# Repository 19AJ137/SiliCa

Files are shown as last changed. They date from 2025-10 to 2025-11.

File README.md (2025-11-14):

# SiliCa

`SiliCa` は、JIS X 6319-4（`FeliCa`）互換の非接触型 IC カードです。  
マイコンとして `ATtiny1616` を採用しており、外部電源を必要とせず、カードリーダからの給電によって動作します。

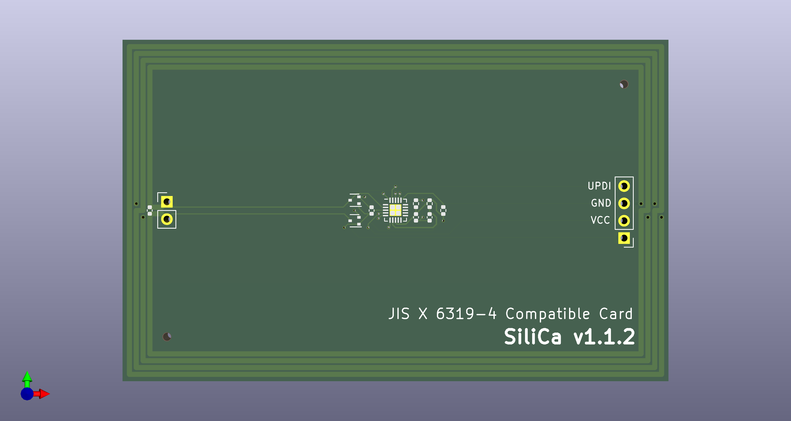
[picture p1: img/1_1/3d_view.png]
3D View


## 概要

`SiliCa` は、最小限のハードウェア構成で、 `FeliCa` プロトコルをファームウェアによって再現し、`FeliCa Standard` や `FeliCa Lite-S` のエミュレーションを実現することを目的としています。

また、`SiliCa` では、実際の `FeliCa` カードで書き換えが不可能な `IDm` やシステムコードなどのパラメータを自由に書き換えることができます。

詳細な仕様や使用方法については、寄稿した同人誌 [rand_r(&v3)](https://techbookfest.org/product/an6q3RzcSM0RcWQBevrEM9) をご参照ください。

## 回路図

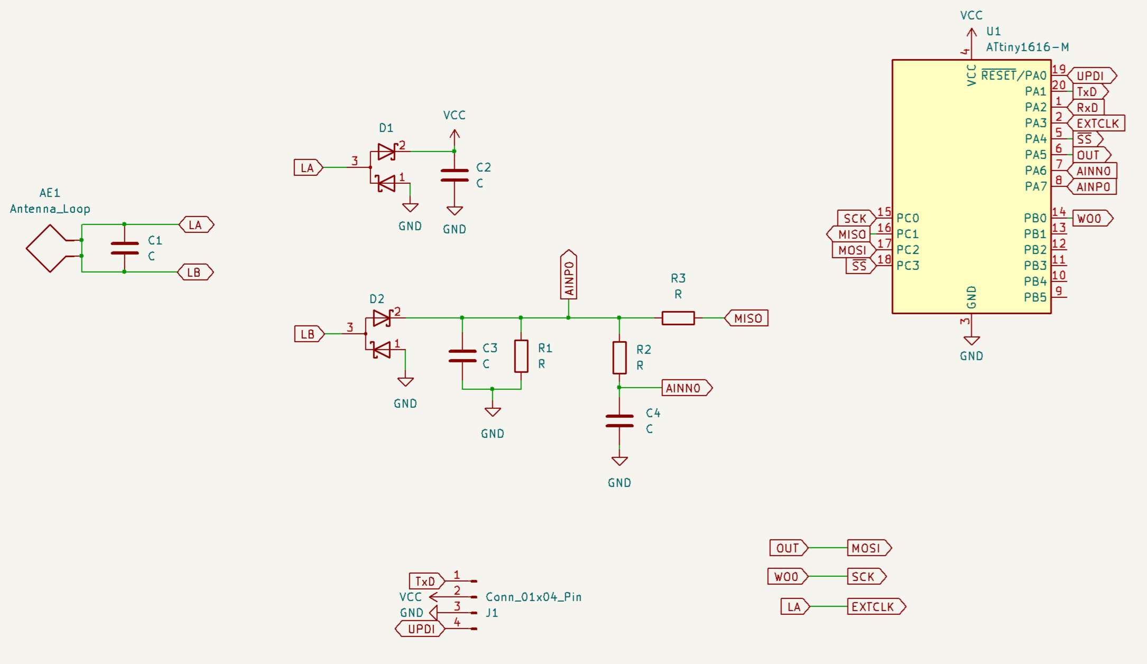
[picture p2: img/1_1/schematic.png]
Schematic


## 注意事項

本プロジェクトは、学術的および実験的な目的で提供されており、商業利用や実際の運用を目的としたものではありません。

---

```
FeliCaは、ソニー株式会社が開発した非接触ICカードの技術方式です。
FeliCaは、ソニーグループ株式会社の登録商標です。
本文では™、®は明記していません。
```

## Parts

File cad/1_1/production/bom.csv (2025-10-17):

Designator | Footprint | Quantity | Value | LCSC Part #
AE1 | PinHeader_1x02_P2.54mm_Vertical | 1 | Antenna_Loop
C1 | 0402 | 4 | C | C1567
C2 | 0402 | 4 | C | C15195
C3 | 0402 | 4 | C | C1523
C4 | 0402 | 4 | C | C1523
D1 | SOT-523 | 2 | D_Schottky_Dual_Series_AKC_Parallel | C2919808
D2 | SOT-523 | 2 | D_Schottky_Dual_Series_AKC_Parallel | C2919808
J1 | PinHeader_1x04_P2.54mm_Vertical | 1 | Conn_01x04_Pin
R1 | 0402 | 3 | R | C11702
R2 | 0402 | 3 | R | C11702
R3 | 0402 | 3 | R | C25123
U1 | VQFN-20-1EP_3x3mm_P0.4mm_EP1.7x1.7mm | 1 | ATtiny1616-M | C507118

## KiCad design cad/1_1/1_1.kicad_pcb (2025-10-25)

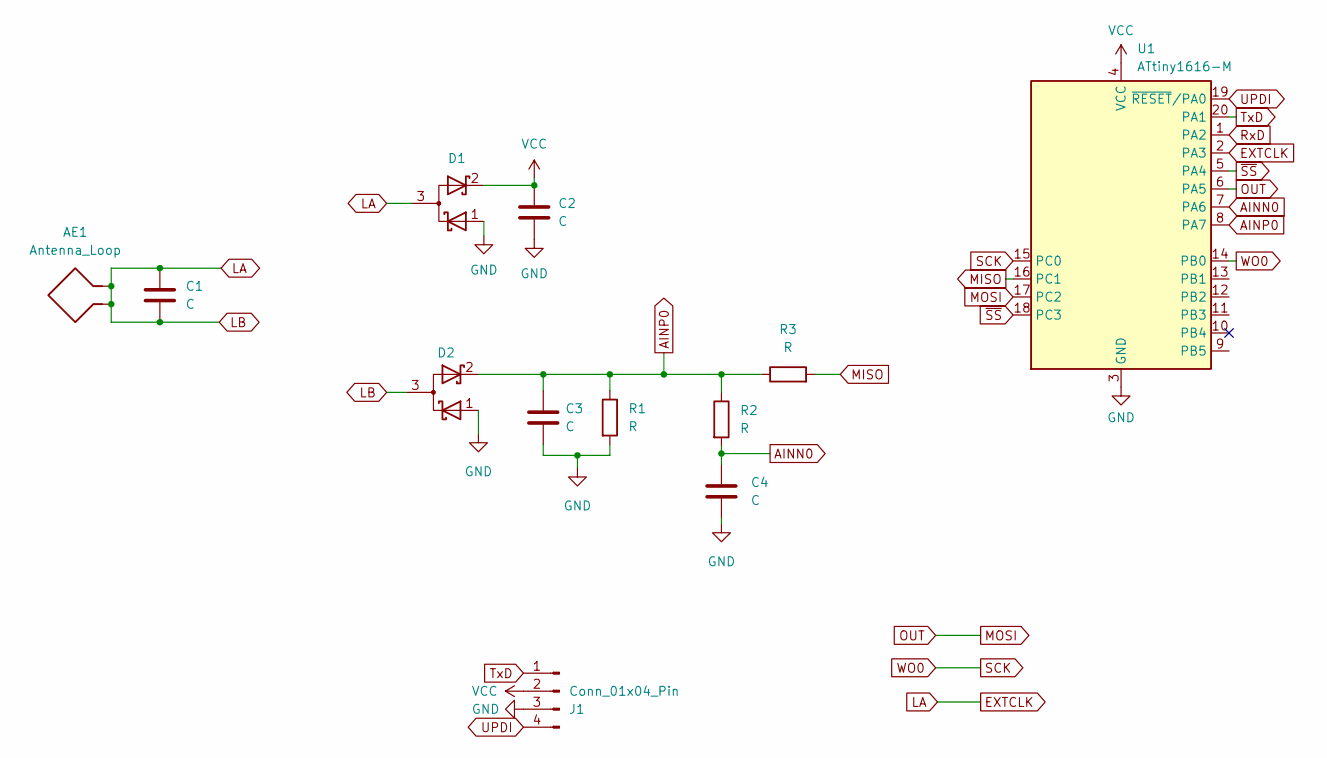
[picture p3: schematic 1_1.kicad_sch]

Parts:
AE1: Antenna_Loop; PinHeader_1x02_P2.54mm_Vertical
C1, C2, C3, C4: C; C_0402_1005Metric
D1, D2: D_Schottky_Dual_Series_AKC_Parallel; SOT-523
J1: Conn_01x04_Pin; PinHeader_1x04_P2.54mm_Vertical
R1, R2, R3: R; R_0402_1005Metric
U1: ATtiny1616-M; VQFN-20-1EP_3x3mm_P0.4mm_EP1.7x1.7mm

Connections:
AINN0: C4.1, R2.2, U1.7 (PA6)
AINP0: C3.1, D2.2 (K), R1.1, R2.1, R3.1, U1.8 (PA7)
EXTCLK: AE1.1, AE1.2, C1.1, C1.2, D1.3 (A), D2.3 (A), U1.2 (PA3)
GND: C2.2, C3.2, C4.2, D1.1 (K), D2.1 (K), J1.3, R1.2, U1.3 (GND), U1.21 (GND)
MISO: R3.2, U1.16 (PC1)
MOSI: U1.6 (PA5), U1.17 (PC2)
RxD: U1.1 (PA2)
SCK: U1.14 (PB0), U1.15 (PC0)
TxD: J1.1, U1.20 (PA1)
UPDI: J1.4, U1.19 (~RESET/PA0)
VCC: C2.1, D1.2 (K), J1.2, U1.4 (VCC)
~SS: U1.5 (PA4), U1.18 (PC3)

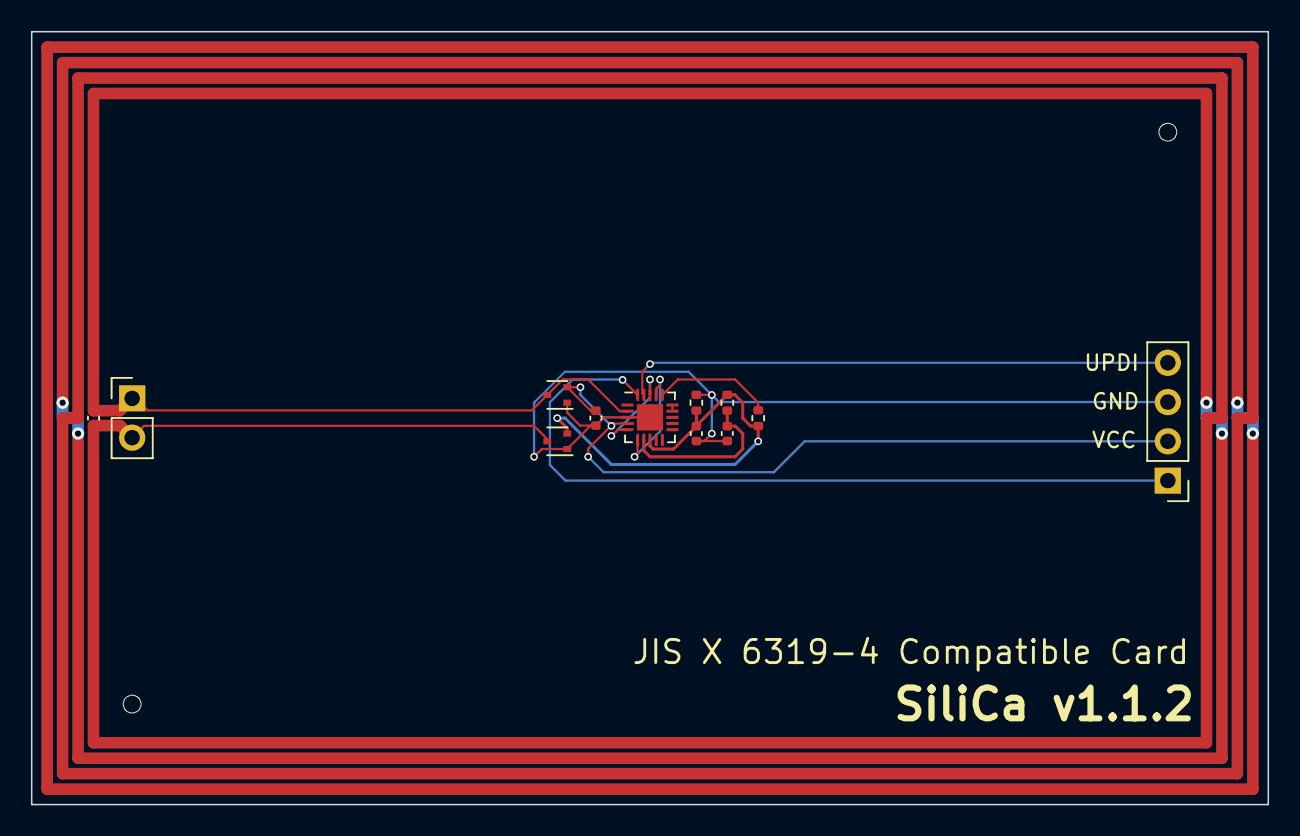
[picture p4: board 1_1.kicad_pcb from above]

Board: 2 copper layers, 80.0 x 50.0 mm, 12 parts (0 on the bottom side), 11 nets.

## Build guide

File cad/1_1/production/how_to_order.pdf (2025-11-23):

how_to_order.md | 2025-11-23

# SiliCaの発注⼿順

JLCPCBでアカウントを作ります

https://jlcpcb.com/

⽇本語訳は不正確な場合があるため、この設定を推奨

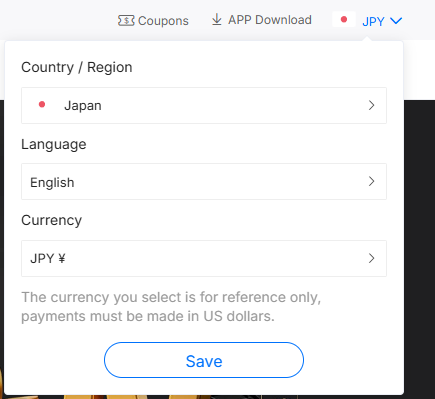
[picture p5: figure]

Order Nowから発注

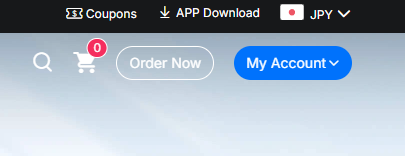
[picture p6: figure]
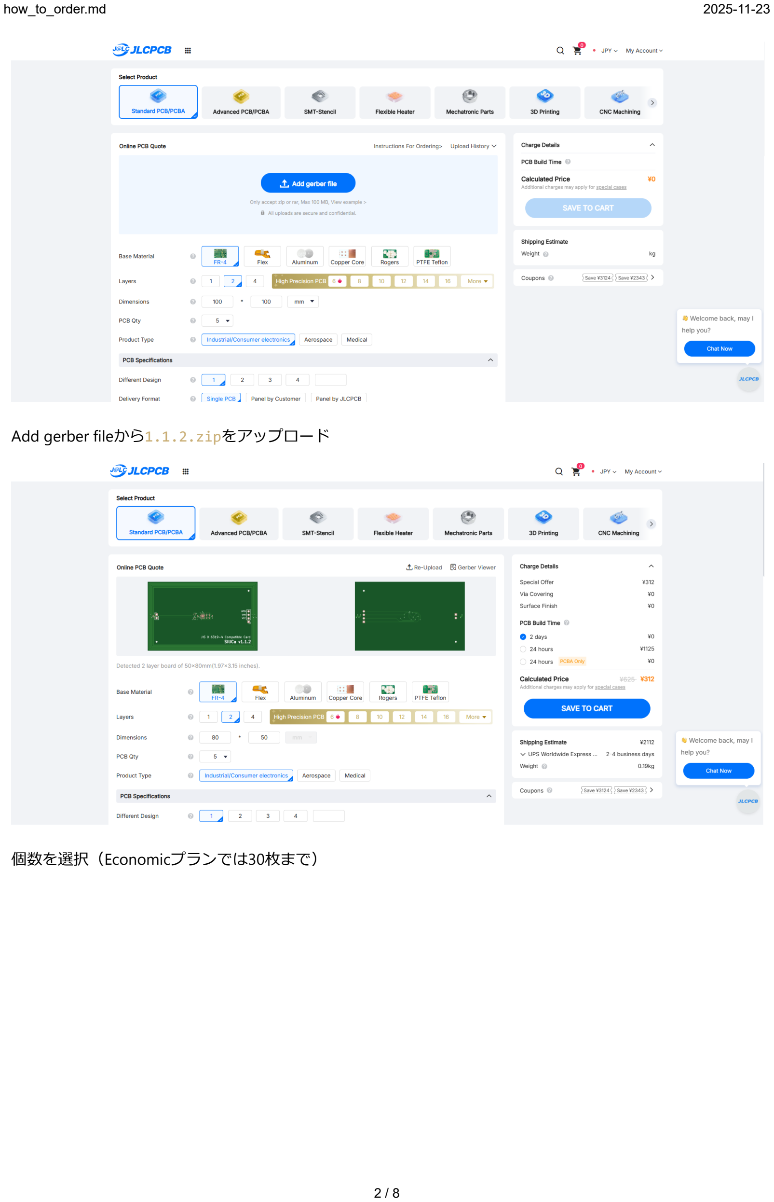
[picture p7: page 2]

Add gerber fileから1.1.2.zipをアップロード

個数を選択（Economicプランでは30枚まで）

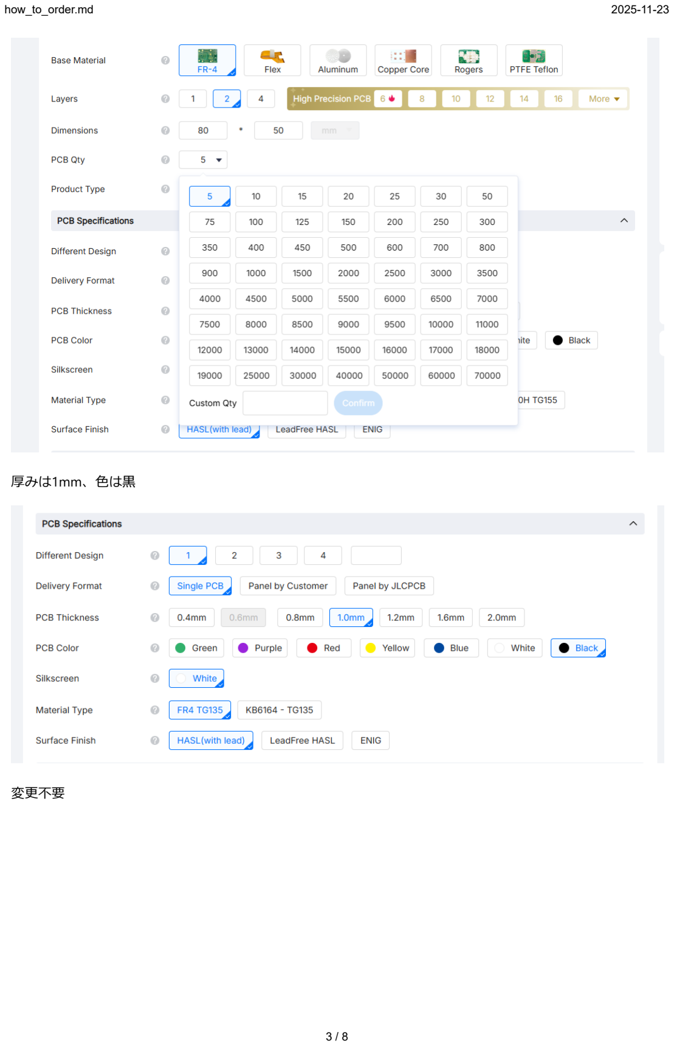
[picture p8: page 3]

厚みは1mm、⾊は⿊

変更不要

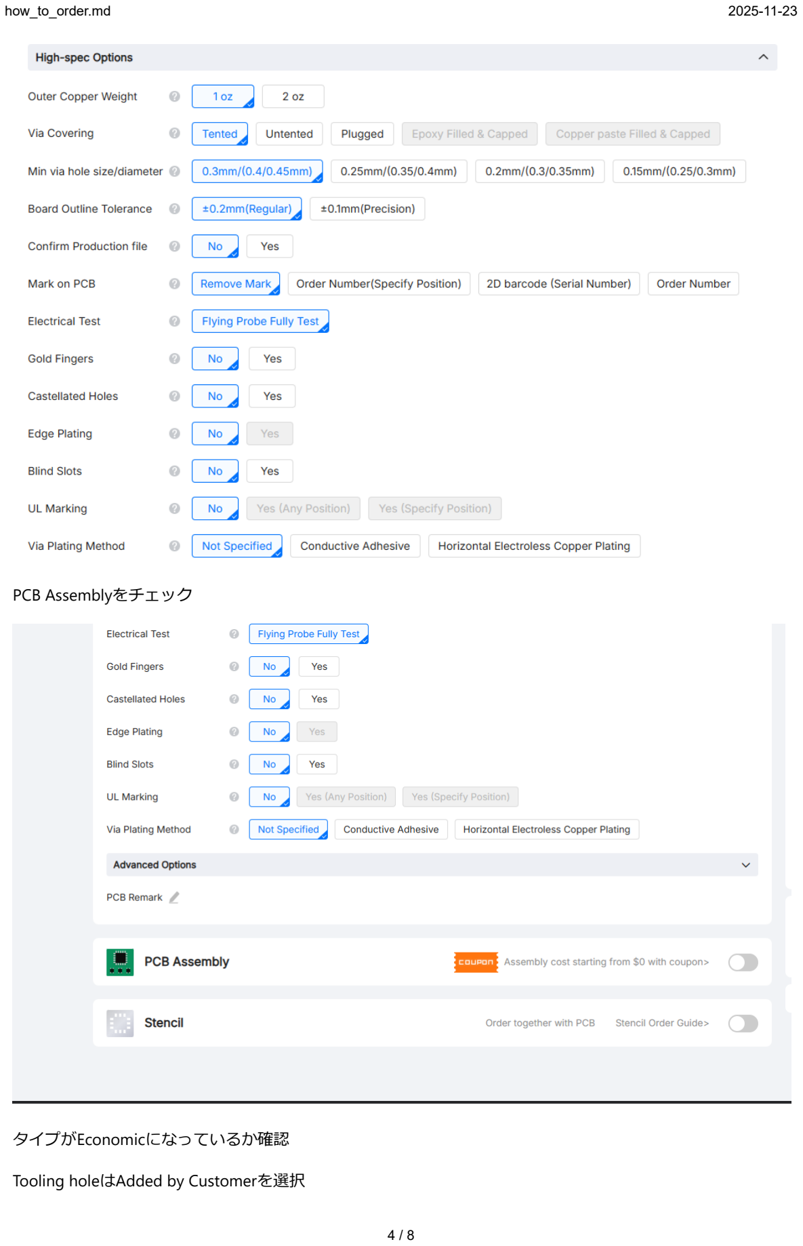
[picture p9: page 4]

PCB Assemblyをチェック

タイプがEconomicになっているか確認

Tooling holeはAdded by Customerを選択

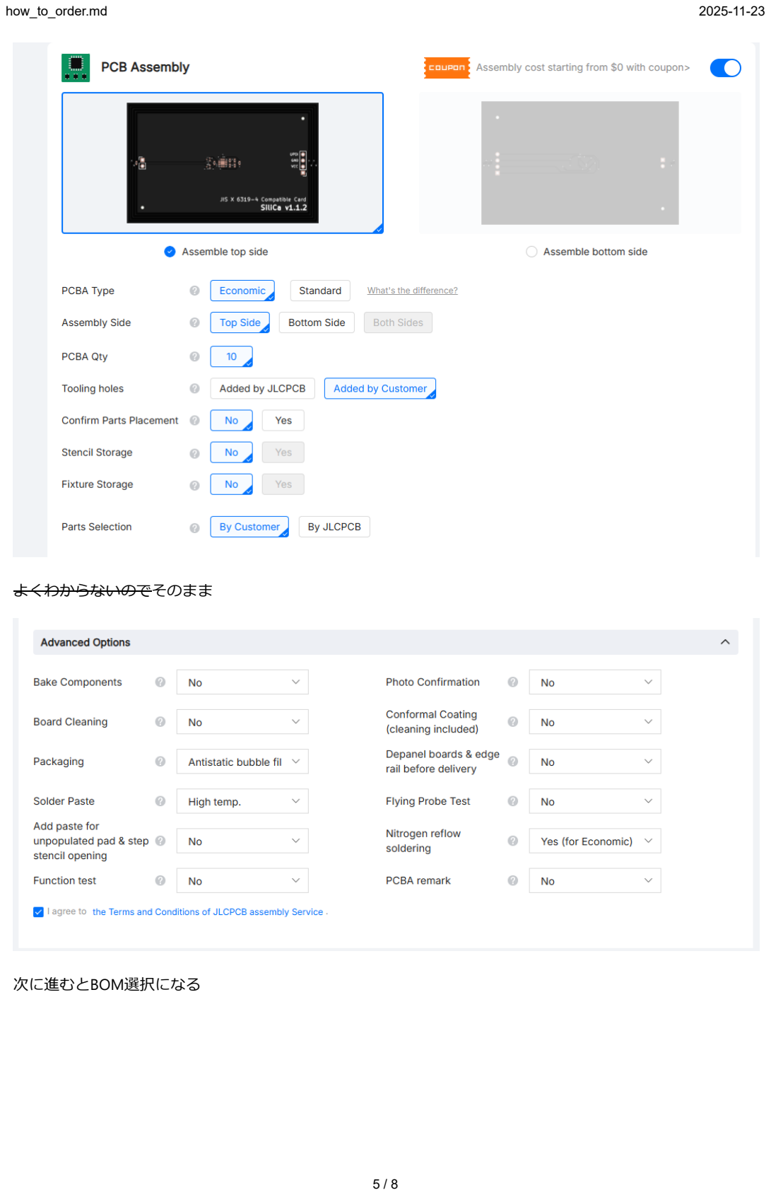
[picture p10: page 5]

よくわからないのでそのまま

次に進むとBOM選択になる

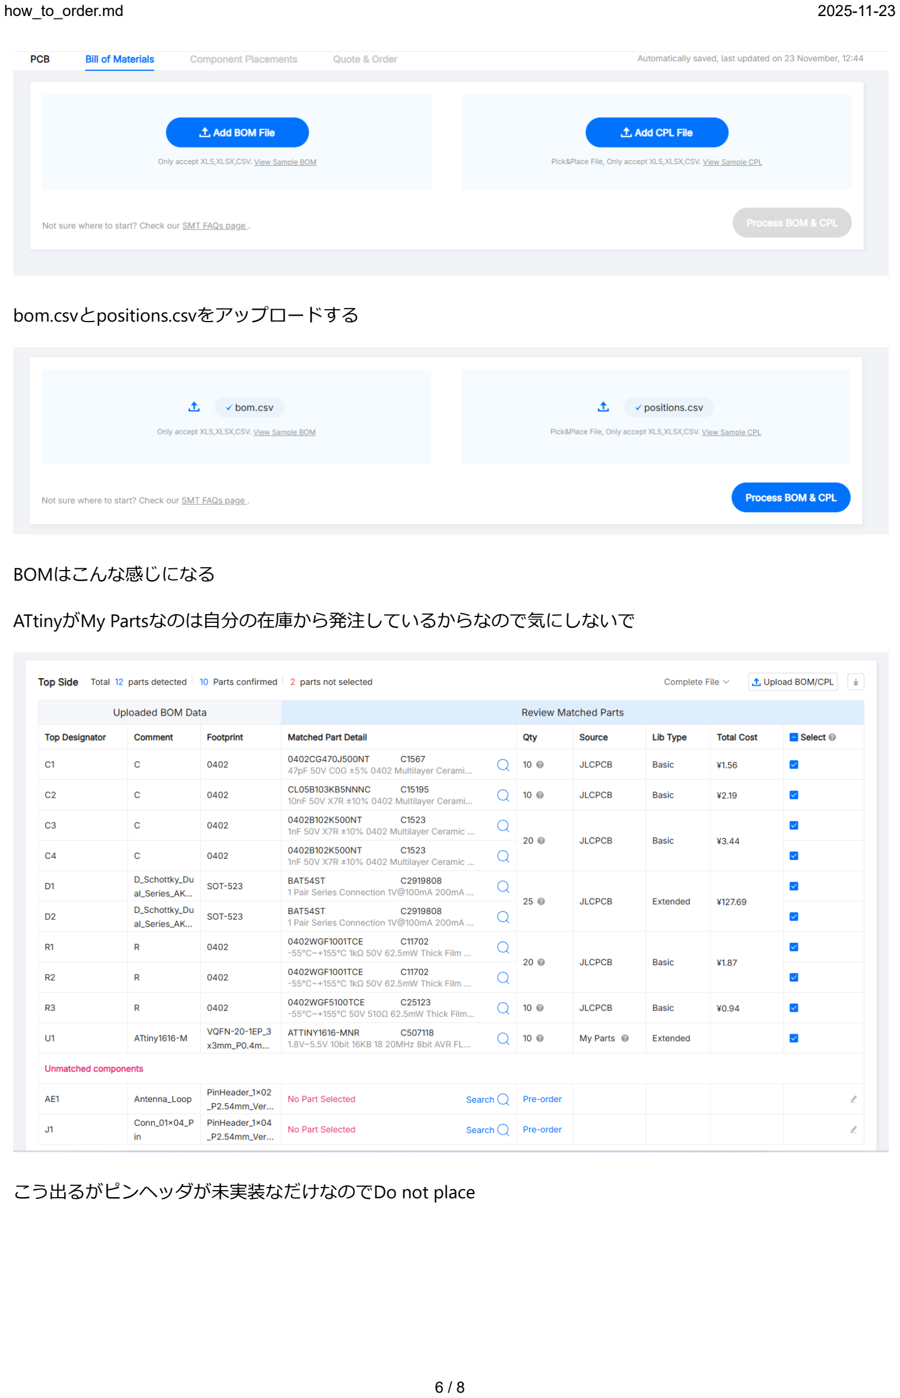
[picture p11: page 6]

bom.csvとpositions.csvをアップロードする

BOMはこんな感じになる
ATtinyがMy Partsなのは⾃分の在庫から発注しているからなので気にしないで

こう出るがピンヘッダが未実装なだけなのでDo not place

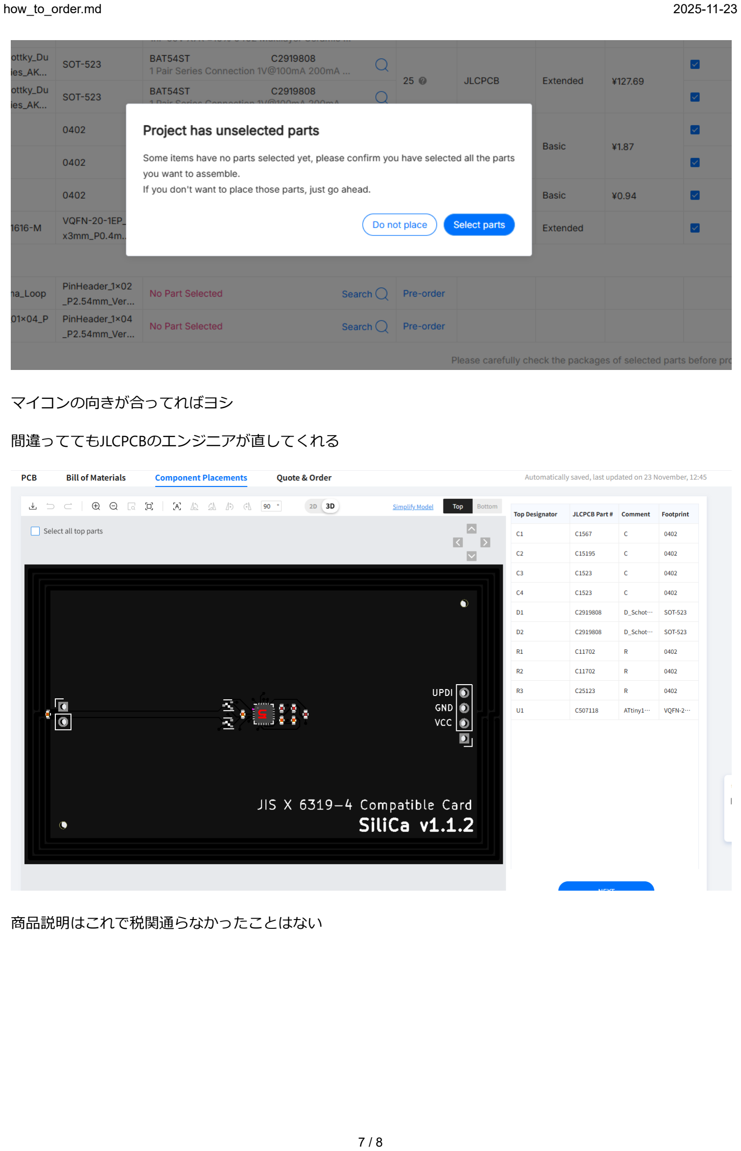
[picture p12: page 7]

マイコンの向きが合ってればヨシ
間違っててもJLCPCBのエンジニアが直してくれる

商品説明はこれで税関通らなかったことはない

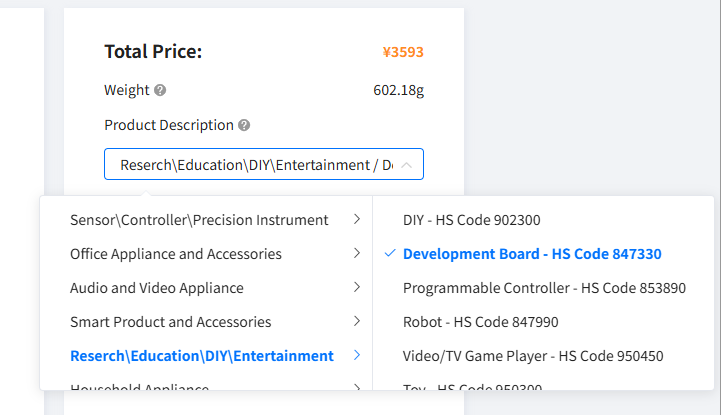
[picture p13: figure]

あとは発送業者を選んで⽀払うだけ
アカウントを登録したてだと豊富にクーポンがあるかもしれないので使っとくのが吉

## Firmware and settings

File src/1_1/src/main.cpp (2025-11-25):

// Implementation of the application layer for
// JIS X 6319-4 compatible card "SiliCa"

#include <stdio.h>
#include <string.h>
#include <avr/eeprom.h>
#include "silica.h"

static constexpr int BLOCK_MAX = 12;
static constexpr int SYSTEM_MAX = 4;
static constexpr int SERVICE_MAX = 4;

constexpr int LAST_ERROR_SIZE = 2;

static uint8_t idm[8];
static uint8_t pmm[8];

static uint8_t EEMEM idm_eep[8];
static uint8_t EEMEM pmm_eep[8];

static uint8_t service_code[2 * SERVICE_MAX];
static uint8_t system_code[2 * SYSTEM_MAX];

static uint8_t EEMEM service_code_eep[2 * SERVICE_MAX];
static uint8_t EEMEM system_code_eep[2 * SYSTEM_MAX];

static uint8_t EEMEM block_data_eep[16 * BLOCK_MAX];

static const int ERROR_BLOCK = 0xE0;
static uint8_t EEMEM last_error_eep[16 * LAST_ERROR_SIZE];

static uint8_t response[0xFF] = {};

void initialize()
{
    // read parameters from EEPROM
    eeprom_read_block(idm, idm_eep, 8);
    eeprom_read_block(pmm, pmm_eep, 8);
    eeprom_read_block(service_code, service_code_eep, 2 * SERVICE_MAX);
    eeprom_read_block(system_code, system_code_eep, 2 * SYSTEM_MAX);
}

bool polling(packet_t command)
{
    // find system code
    int system_index = -1;
    for (int i = 0; i < SYSTEM_MAX; i++)
    {
        uint8_t sc1 = system_code[2 * i];
        uint8_t sc2 = system_code[2 * i + 1];

        if (sc1 == 0 && sc2 == 0)
            break;

        if ((command[2] == sc1 || command[2] == 0xFF) && (command[3] == sc2 || command[3] == 0xFF))
        {
            system_index = i;
            break;
        }
    }

    // avoid bricking cards
    if (command[2] == 0xFF && command[3] == 0xFF)
    {
        system_index = 0;
    }

    if (system_index == -1)
        return false;

    uint8_t request_code = command[4];
    if (request_code == 0x00)
        response[0] = 18;
    else
        response[0] = 20;

    if (request_code > 0x02)
        return false;

    // response code
    response[1] = 0x01;

    // time slot (unused)
    int n = command[5];

    memcpy(response + 2, idm, 8);
    memcpy(response + 10, pmm, 8);

    if (system_index > 0)
    {
        // update the top nibble of IDm with the system index
        response[2] = (system_index << 4) | (response[2] & 0x0F);
    }

    // system code request
    if (request_code == 0x01)
    {
        memcpy(response + 18, system_code + 2 * system_index, 2);
    }
    // communication performance request
    if (request_code == 0x02)
    {
        response[18] = 0x00; // reserved
        response[19] = 0x01; // only 212kbps communication is supported
    }

    return true;
}

bool request_service(packet_t command)
{
    if (command[0] < 11)
        return false;

    // number of nodes
    int n = command[10];
    if (!(1 <= n && n <= 32))
        return false;

    response[0] = 11 + 2 * n;

    response[10] = n;

    // always return key version 0
    for (int i = 0; i < n; i++)
    {
        response[11 + 2 * i] = 0x00;
        response[12 + 2 * i] = 0x00;
    }

    return true;
}

int parse_block_list(int n, const uint8_t *block_list, uint8_t *block_nums)
{
    int j = 0;
    for (int i = 0; i < n; i++)
    {
        if (block_list[j] == 0x80)
        {
            // 2-byte block list element
            block_nums[i] = block_list[j + 1];
            j += 2;
        }
        else if (block_list[j] == 0x00)
        {
            // 3-byte block list element
            if (block_list[j + 2] != 0x00)
                return 0;
            block_nums[i] = block_list[j + 1];
            j += 3;
        }
        else
        {
            return 0;
        }
    }
    // size of block list
    return j;
}

bool read_without_encryption(packet_t command)
{
    // check length
    if (command[0] < 16)
        return false;

    // number of services
    int m = command[10];

    if (m != 1)
    {
        response[0] = 12;    // length
        response[10] = 0xFF; // status flag 1
        response[11] = 0xA1; // status flag 2

        return true;
    }

    uint16_t target_service_code = command[11] | (command[12] << 8);

    // number of blocks
    int n = command[13];

    // find service code
    bool service_found = false;
    for (int i = 0; i < SERVICE_MAX; i++)
    {
        uint16_t sc = service_code[2 * i] | (service_code[2 * i + 1] << 8);
        if (sc == 0)
            break;

        if (target_service_code == sc)
        {
            service_found = true;
            break;
        }
    }

    if (target_service_code == 0xFFFF)
    {
        service_found = true;
    }

    if (!service_found)
    {
        response[0] = 12;    // length
        response[10] = 0xFF; // status flag 1
        response[11] = 0xA6; // status flag 2

        return true;
    }

    if (!(1 <= n && n <= BLOCK_MAX))
    {
        response[0] = 12;    // length
        response[10] = 0xFF; // status flag 1
        response[11] = 0xA2; // status flag 2

        return true;
    }

    uint8_t block_nums[BLOCK_MAX];
    if (parse_block_list(n, command + 14, block_nums) == 0)
    {
        response[0] = 12;    // length
        response[10] = 0xFF; // status flag 1
        response[11] = 0xA6; // status flag 2
        return true;
    }

    // load block data from EEPROM
    for (int i = 0; i < n; i++)
    {
        int block_num = block_nums[i];

        bool valid_block = false;

        if (block_num < BLOCK_MAX)
        {
            valid_block = true;
            eeprom_read_block(response + 13 + 16 * i, block_data_eep + 16 * block_num, 16);
        }
        if (ERROR_BLOCK <= block_num && block_num < ERROR_BLOCK + LAST_ERROR_SIZE)
        {
            valid_block = true;
            eeprom_read_block(response + 13 + 16 * i, last_error_eep + (block_num - ERROR_BLOCK) * 16, 16);
        }
        // D_ID
        if (n == 1 && block_num == 0x83)
        {
            valid_block = true;
            memcpy(response + 13, idm, 8);
            memcpy(response + 21, pmm, 8);
        }
        // SER_C
        if (n == 1 && block_num == 0x84)
        {
            valid_block = true;
            memcpy(response + 13, service_code, 2 * SERVICE_MAX);
            memset(response + 13 + 2 * SERVICE_MAX, 0x00, 16 - 2 * SERVICE_MAX);
        }
        // SYS_C
        if (n == 1 && block_num == 0x85)
        {
            valid_block = true;
            memcpy(response + 13, system_code, 2 * SYSTEM_MAX);
            memset(response + 13 + 2 * SYSTEM_MAX, 0x00, 16 - 2 * SYSTEM_MAX);
        }

        if (!valid_block)
        {
            response[0] = 12;    // length
            response[10] = 0xFF; // status flag 1
            response[11] = 0xA8; // status flag 2
            return true;
        }
    }

    response[0] = 13 + 16 * n; // length

    response[10] = 0x00; // status flag 1
    response[11] = 0x00; // status flag 2

    response[12] = n; // number of blocks

    return true;
}

bool write_without_encryption(packet_t command)
{
    int len = command[0];
    int m = command[10]; // number of services
    uint16_t target_service_code = command[11] | (command[12] << 8);
    int n = command[13]; // number of blocks

    if (len < 32)
        return false;

    if (m != 1)
    {
        response[0] = 12;    // length
        response[10] = 0xFF; // status flag 1
        response[11] = 0xA1; // status flag 2

        return true;
    }

    if (!(1 <= n && n <= BLOCK_MAX))
    {
        response[0] = 12;    // length
        response[10] = 0xFF; // status flag 1
        response[11] = 0xA2; // status flag 2
        return true;
    }

    uint8_t block_nums[BLOCK_MAX];
    int N = parse_block_list(n, command + 14, block_nums);

    if (N == 0)
    {
        response[0] = 12;    // length
        response[10] = 0xFF; // status flag 1
        response[11] = 0xA6; // status flag 2
        return true;
    }

    // check length
    if (len != 14 + N + 16 * n)
        return false;

    // write block data to EEPROM
    for (int i = 0; i < n; i++)
    {
        int block_num = block_nums[i];

        bool valid_block = false;

        if (block_num < BLOCK_MAX)
        {
            valid_block = true;
            eeprom_update_block(command + 14 + N + 16 * i, block_data_eep + 16 * block_num, 16);
        }

        // D_ID
        if (n == 1 && block_num == 0x83)
        {
            valid_block = true;

            // Update IDm
            memcpy(idm, command + 16, 8);
            eeprom_update_block(idm, idm_eep, 8);

            // Update PMm
            memcpy(pmm, command + 24, 8);
            eeprom_update_block(pmm, pmm_eep, 8);
        }

        // SER_C
        if (n == 1 && block_num == 0x84)
        {
            valid_block = true;

            memcpy(service_code, command + 16, 2 * SERVICE_MAX);
            eeprom_update_block(service_code, service_code_eep, 2 * SERVICE_MAX);
        }

        // SYS_C
        if (n == 1 && block_num == 0x85)
        {
            valid_block = true;

            memcpy(system_code, command + 16, 2 * SYSTEM_MAX);
            eeprom_update_block(system_code, system_code_eep, 2 * SYSTEM_MAX);
        }

        if (!valid_block)
        {
            response[0] = 12;    // length
            response[10] = 0xFF; // status flag 1
            response[11] = 0xA8; // status flag 2
            return true;
        }
    }

    response[0] = 12; // length

    response[10] = 0x00; // status flag 1
    response[11] = 0x00; // status flag 2

    return true;
}

bool search_service_code(int index)
{
    response[0] = 12;

    if (index < 0 || index >= SERVICE_MAX)
    {
        response[10] = 0xFF;
        response[11] = 0xFF;
        return true;
    }

    uint8_t sc1 = service_code[2 * index];
    uint8_t sc2 = service_code[2 * index + 1];

    if (sc1 == 0x00 && sc2 == 0x00)
    {
        response[10] = 0xFF;
        response[11] = 0xFF;
        return true;
    }

    response[10] = sc1;
    response[11] = sc2;

    return true;
}

bool request_system_code()
{
    int n = 0;

    for (int i = 0; i < SYSTEM_MAX; i++)
    {
        uint8_t sc1 = system_code[2 * i];
        uint8_t sc2 = system_code[2 * i + 1];

        if (sc1 == 0x00 && sc2 == 0x00)
            break;

        response[11 + 2 * i] = sc1;
        response[12 + 2 * i] = sc2;
        n++;
    }

    response[0] = 11 + 2 * n;
    response[10] = n;
    return n != 0;
}

// process application layer command and generate response
packet_t process(packet_t command)
{
    if (command == nullptr)
        return nullptr;

    const int len = command[0];
    const uint8_t command_code = command[1];

    // Polling
    if (command_code == 0x00)
    {
        if (polling(command))
            return response;
        else
            return nullptr;
    }

    // Echo
    if (command[1] == 0xF0 && command[2] == 0x00)
    {
        memcpy(response, command, len);
        return response;
    }

    // verify the tail of IDm matches
    if ((command[2] & 0x0F) != (idm[0] & 0x0F))
        return nullptr;
    if (memcmp(command + 3, idm + 1, 7) != 0)
        return nullptr;

    // check command code
    if (command_code % 2 != 0)
        return nullptr;

    // set response code
    response[1] = command_code + 1;

    // copy IDm from command to response
    memcpy(response + 2, command + 2, 8);

    switch (command_code)
    {
    case 0x02: // Request Service
        if (!request_service(command))
            return nullptr;
        break;
    case 0x04: // Request Response
        if (len != 10)
            return nullptr;

        response[0] = 11;
        response[10] = 0x00;

        break;
    case 0x06: // Read Without Encryption
        if (!read_without_encryption(command))
            return nullptr;
        // status flag 1
        if (response[10] != 0x00)
        {
            save_error(command);
            Serial_println("Read failed");
            print_packet(command);
        }
        break;
    case 0x08: // Write Without Encryption
        if (!write_without_encryption(command))
            return nullptr;
        break;
    case 0x0A: // Search Service Code
    {
        // Define in switch is prohibited in C++
        // use a block here
        if (len != 12)
            return nullptr;

        int index = command[10] | (command[11] << 8);
        search_service_code(index);
    }
    break;
    case 0x0C: // Request System Code
        if (len != 10)
            return nullptr;
        if (!request_system_code())
            return nullptr;
        break;
    case 0x10: // Authentication1
    // pass through for unsupported commands
    default:
        return nullptr;
    }

    return response;
}

void save_error(packet_t command)
{
    int len = command[0];
    if (len > sizeof(last_error_eep))
        len = sizeof(last_error_eep);

    eeprom_update_block(command, last_error_eep, len);
}

// Debug: print packet to serial
void print_packet(packet_t packet)
{
    int len = packet[0];
    if (len == 0)
    {
        Serial_println("<empty>");
        return;
    }

    for (int i = 1; i < len; i++)
    {
        char hex_str[5];
        sprintf(hex_str, "%02X", packet[i]);
        Serial_print(hex_str);
        if (i != len - 1)
            Serial_print(" ");
    }
    Serial_println("");
}

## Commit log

2025-10-17 copy KiCad files
    [1_1.kicad_pcb, 1_1.kicad_sch, bom.csv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]
2025-10-17 move files
    [1_1.kicad_pcb, 1_1.kicad_sch, bom.csv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]
2025-10-18 rename dump_command to print_packet and update parameter usage
2025-10-19 fix: update service_code_eep to pointer type and adjust EEPROM read/write calls
    [main.cpp]
2025-10-19 fix: validate command length in process function to prevent errors
    [main.cpp]
2025-10-21 fix: correct service_code_eep pointer usage and adjust variable visibility
    [main.cpp]
2025-10-21 fix: update status flag in response and improve error logging for read/write operations
    [main.cpp]
2025-10-22 fix: update hysteresis setting for Analog Comparator 0 to 50mV
    [silica.cpp]
2025-10-23 feat: add ADC configuration and hysteresis adjustment for improved voltage reference handling
2025-10-23 fix: adjust hysteresis settings for Analog Comparator based on reference value
    [silica.cpp]
2025-10-25 move UPDI wire to back
    [1_1.kicad_pcb]
2025-10-25 fix: update version number to 1.1.2 in PCB layout
    [1_1.kicad_pcb]
2025-10-25 add tooling holes
    [1_1.kicad_pcb]
2025-10-25 move tooling holes
    [1_1.kicad_pcb]
2025-10-25 refactor: remove unused reference text and reset active layer to default
    [1_1.kicad_pcb]
2025-10-25 refactor: remove unused no_connect element from schematic
    [1_1.kicad_sch]
2025-10-25 refactor: fix SPI_transfer function signature and update calls in enable_transmit
    [silica.cpp]
2025-10-28 refactor: enhance frame capture and synchronization logic in receive_command
2025-10-28 refactor: improve packet length validation and error handling in receive_command
    [main.cpp, silica.cpp]
2025-11-03 fix: update U1 rotation in positions.csv from 0.0 to 270.0
    [positions.csv]
2025-11-12 feat: implement request_service function and integrate into process command flow
